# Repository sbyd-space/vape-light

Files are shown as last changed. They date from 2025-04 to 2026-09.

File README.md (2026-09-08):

# vape flashlight
An educational DIY kit for converting a disposable vape into a rechargeable flashlight

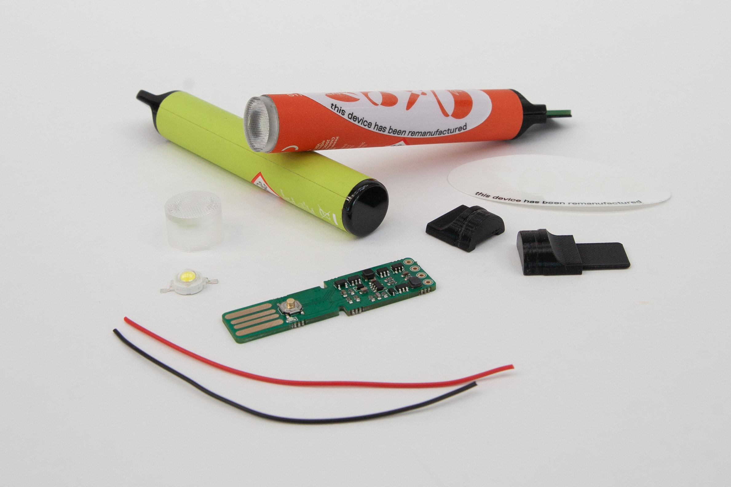
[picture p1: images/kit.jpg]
photograph of an early version of the kit

*early prototype of the kit photographed by Daniel Wilkens, used under CC BY 4.0 / cropped from original*

The kit is used in workshops to educate about:
* environmental and social impact of resource extraction
* resource consumption of electronics and disposable products
* basic hands-on soldering skills

It is accompanied by a [zine][zine] containing contextual information about these topics and instructions for assembly.

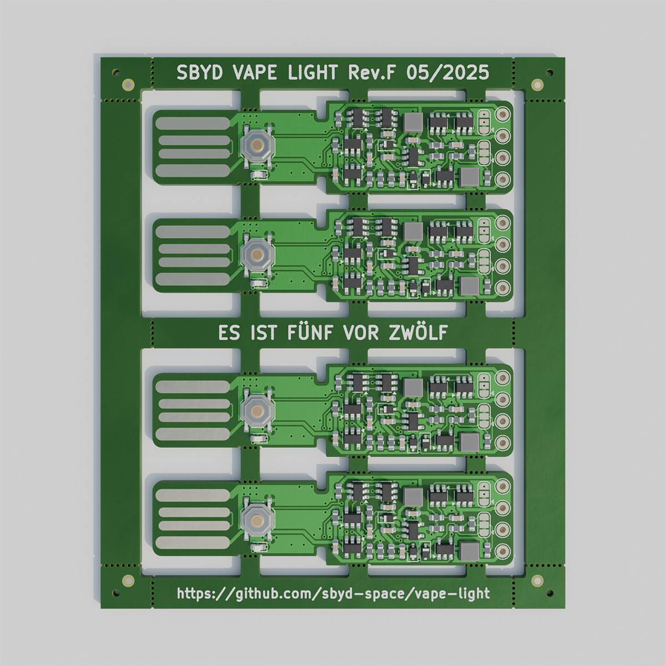
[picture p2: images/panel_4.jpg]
rendering of the pcb

*rendering of the pcb by Steffen Hartwig, licensed under CC BY 4.0*

The pcbs were developed with [KiCad 8.0][kicad].  
[KiKit 1.6.0][kikit] was used for the panelization of the PCBs for production.  
Visualizations were made with [Blender 4.2][blender] and [pcb2blender 2.15][pcb2blender].  
The fabrication files were generated with [Fabrication Toolkit 5.0.1][fabricationtoolkit].  
The files for 3D printing were generated from [OpenSCAD 2021.01][openscad].  

PCB and 3D printing source files are licensed under **CERN OHL P 2.0**  
Images and visualizations are licensed under **CC BY 4.0** 




The kit, workshop and zine were developed in the project ["Sustainability by Design"][sbyd] as part of the “Innovative University” funding line and is supported by the German Federal Ministry of Research, Technology and Space (BMFTR) and the Joint Science Conference (GWK).

[zine]: https://sbyd.space/wp-content/uploads/2024/09/SBYD-Zine_3_WEB.pdf
[sbyd]: https://sbyd.space/en/

[kicad]: https://www.kicad.org
[kikit]: https://github.com/yaqwsx/KiKit
[blender]: https://www.blender.org
[pcb2blender]: https://github.com/30350n/pcb2blender
[fabricationtoolkit]: https://github.com/bennymeg/JLC-Plugin-for-KiCad
[openscad]: https://openscad.org

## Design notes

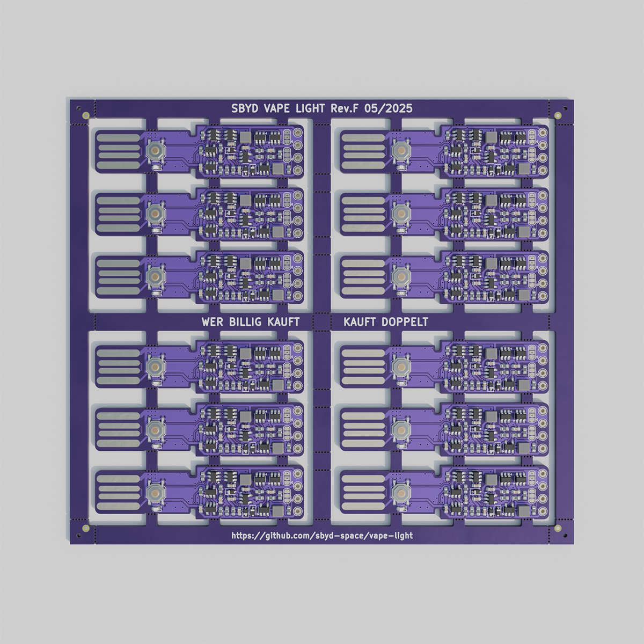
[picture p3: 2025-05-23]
images/panel_12.jpg

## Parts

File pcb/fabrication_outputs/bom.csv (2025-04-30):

Designator | Footprint | Quantity | Value | LCSC Part #
0-C1, 0-C6, 0-C7, 1-C1, 1-C6, 1-C7, 2-C1, 2-C6, 2-C7, 3-C1, 3-C6, 3-C7 | 0603 | 12 | 100n | C14663
0-C2, 1-C2, 2-C2, 3-C2 | 0603 | 4 | 1u | C15849
0-C3, 1-C3, 2-C3, 3-C3 | 0603 | 4 | 10u | C96446
0-C4, 1-C4, 2-C4, 3-C4 | 0603 | 4 | 150p | C1594
0-C5, 1-C5, 2-C5, 3-C5 | 0603 | 4 | 2u2 | C23630
0-D2, 1-D2, 2-D2, 3-D2 | 0603 | 4 | LED | C2286
0-D3, 0-D4, 0-D5, 1-D3, 1-D4, 1-D5, 2-D3, 2-D4, 2-D5, 3-D3, 3-D4, 3-D5 | D_SOD-323 | 12 | D_Schottky | C191023
0-L1, 1-L1, 2-L1, 3-L1 | L_3x3 | 4 | 47uH | C370426
0-L2, 1-L2, 2-L2, 3-L2 | L_3x3 | 4 | 10uH | C45403
0-Q1, 1-Q1, 2-Q1, 3-Q1 | SOT-23-6 | 4 | FS8205A | C2830320
0-R1, 1-R1, 2-R1, 3-R1 | 0603 | 4 | 180 | C22828
0-R10, 1-R10, 2-R10, 3-R10 | 0603 | 4 | 1 | C22936
0-R11, 1-R11, 2-R11, 3-R11 | 0603 | 4 | 330m | C2934252
0-R2, 1-R2, 2-R2, 3-R2 | 0603 | 4 | 5k6 | C23189
0-R3, 1-R3, 2-R3, 3-R3 | 0603 | 4 | 1k | C21190
0-R4, 1-R4, 2-R4, 3-R4 | 0603 | 4 | 100 | C22775
0-R5, 1-R5, 2-R5, 3-R5 | 0603 | 4 | 10k | C25804
0-R6, 1-R6, 2-R6, 3-R6 | 0603 | 4 | 680m | C5126049
0-R7, 1-R7, 2-R7, 3-R7 | 0603 | 4 | 13K | C22797
0-R8, 1-R8, 2-R8, 3-R8 | 0603 | 4 | 150k | C22807
0-R9, 1-R9, 2-R9, 3-R9 | 0603 | 4 | 10k | C25804
0-SW1, 1-SW1, 2-SW1, 3-SW1 | SW_Push_1P1T_XKB_TS-1187A | 4 | SW_Push | C571338
0-U1, 1-U1, 2-U1, 3-U1 | SOT-23-6 | 4 | DW01A | C2927799
0-U2, 1-U2, 2-U2, 3-U2 | SOT-23-5 | 4 | LTC4054ES5-4.2 | C478383
0-U3, 1-U3, 2-U3, 3-U3 | SOT-23-5 | 4 | LM27313XMF | C341750
0-U4, 1-U4, 2-U4, 3-U4 | SOT-23-6 | 4 | 74LVC2G14 | C5375976
0-U5, 1-U5, 2-U5, 3-U5 | SOT-23-6 | 4 | 74LVC1G175 | C128412
0-U6, 1-U6, 2-U6, 3-U6 | TSOT-23-5 | 4 | AL8860WT | C125330
0-U7, 1-U7, 2-U7, 3-U7 | SOT-23-5 | 4 | 74LVC1G02 | C16360

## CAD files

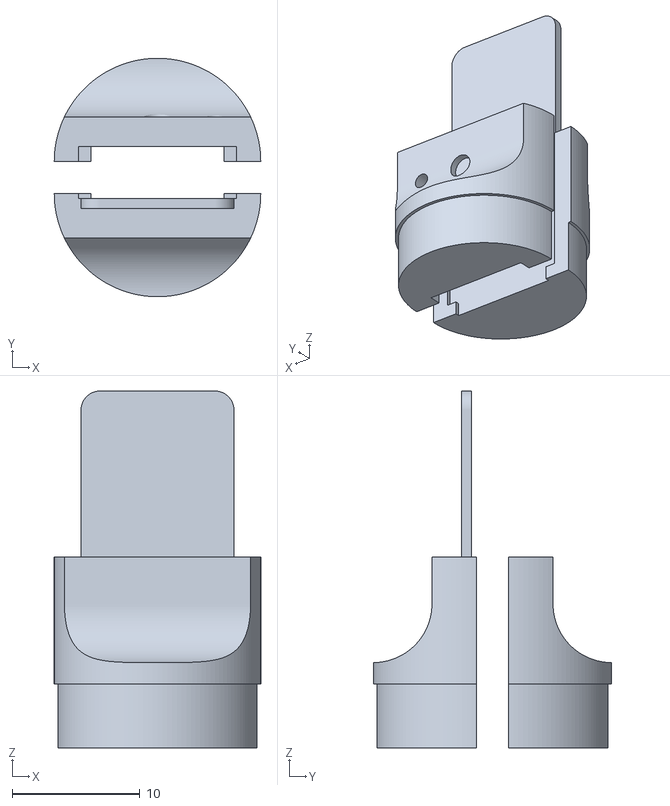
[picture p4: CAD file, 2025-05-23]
pcb/fabrication_outputs/vapelight.stl
16.2 x 18.7 x 28.0

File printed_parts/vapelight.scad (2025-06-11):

// for PCB revision F
// 06/2025

//part of https://github.com/sbyd-space/vape-light

//License: CC BY 4.0
//https://creativecommons.org/licenses/by/4.0/

$fn=128;  //resolution

h_lower=5; //length of lower part inside the tube
d_lower=15.6; //diameter of lower part inside the tube
thickness_end=7; //thickness of upper end

d_upper=16.2; //diameter of rim of upper part
r_fillet=(d_upper-thickness_end)/2; //radius of the big fillet
h_rim=1.7; //thickness of the rim sitting on the end of the tube
h_upper=10; //overall height of upper part

d_button=2.2; //diameter of button hole
h_button=6; //height of button above tube


 difference(){ //part 1
     union(){ //main body
        translate([0,0,0])cylinder(h=h_upper,r=d_upper/2); //upper part
        translate([0,0,-h_lower])cylinder(h=h_lower,r=d_lower/2); //lower part
    }
    translate([0,r_fillet+thickness_end/2,r_fillet+h_rim])rotate([0,90,0])translate([0,0,-50])cylinder(h=100,r=r_fillet); //cutter for big fillet
    translate([0,thickness_end/2,h_rim+r_fillet])translate([-50,0,0])cube([100,100,100]); //cutting cube above fillet

    //cutout for pcb:
    translate([-6.2,-.4,-3.75])cube([12.4,1.6,10+3.75]);
    translate([-5.2,-.4,-5])cube([10.4,1.6,1.5]);
    
        
    translate([0,0,h_button])rotate([-90,0,0])cylinder(h=d_upper/2,r=d_button/2); // cutout for button cap
    hull(){ // cutout for button body and legs
        translate([-1.6,1.2,h_button])rotate([-90,0,0])cylinder(h=1.6,r1=3.35,r2=2.6);
        translate([1.6,1.2,h_button])rotate([-90,0,0])cylinder(h=1.6,r1=3.35,r2=2.6);
    }
    translate([4.5,0,h_button])rotate([-90,0,0])cylinder(h=10,r=0.7);// cutout for led
    translate([4.5,1.2,h_button])rotate([-90,0,0])cylinder(h=1,r1=1.3, r2=0.7);// cutout for led body
    
    translate([-25,-50,-25])cube([50,50,50]); //cutter cube for unused half
}


 translate([0,-2.5,0])   //separate parts for printing 
 difference(){ //part 2
    union(){ //main body
        translate([0,0,0])cylinder(h=h_upper,r=d_upper/2); //upper part
        translate([0,0,-h_lower])cylinder(h=h_lower,r=d_lower/2); //lower part
        union() { //pcb support plate
            translate([-6,-1.2,h_upper])cube([12,.8,11.5]);   
            translate([-4.5,-1.2,h_upper])cube([9,.8,13]);  
            translate([-4.5,-1.2,h_upper+11.5])rotate([-90,0,0])cylinder(h=.8,r=1.5);  //radiussed corner
            translate([4.5,-1.2,h_upper+11.5])rotate([-90,0,0])cylinder(h=.8,r=1.5);   //radiussed corner
        }        
    }
    mirror([0,1,0]) { //mirrored from other side
        translate([0,r_fillet+thickness_end/2,r_fillet+h_rim])rotate([0,90,0])translate([0,0,-50])cylinder(h=100,r=r_fillet); //cutter for big fillet
        translate([0,thickness_end/2,h_rim+r_fillet])translate([-50,0,0])cube([100,100,100]); //cutting cube above fillet
    }
 
    //cutout for pcb:
    translate([-6.2,-.4,-3.75])cube([12.4,1.6,10+3.75]);
    translate([-5.2,-.4,-5])cube([10.4,1.6,1.5]);
    
    translate([-25,0,-25])cube([50,50,50]); //cutter cube for unused half
}

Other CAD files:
printed_parts/vapelight_e800.stl
printed_parts/vapelight_e600.stl
printed_parts/vapelight_e600.scad
printed_parts/vapelight_e800.scad

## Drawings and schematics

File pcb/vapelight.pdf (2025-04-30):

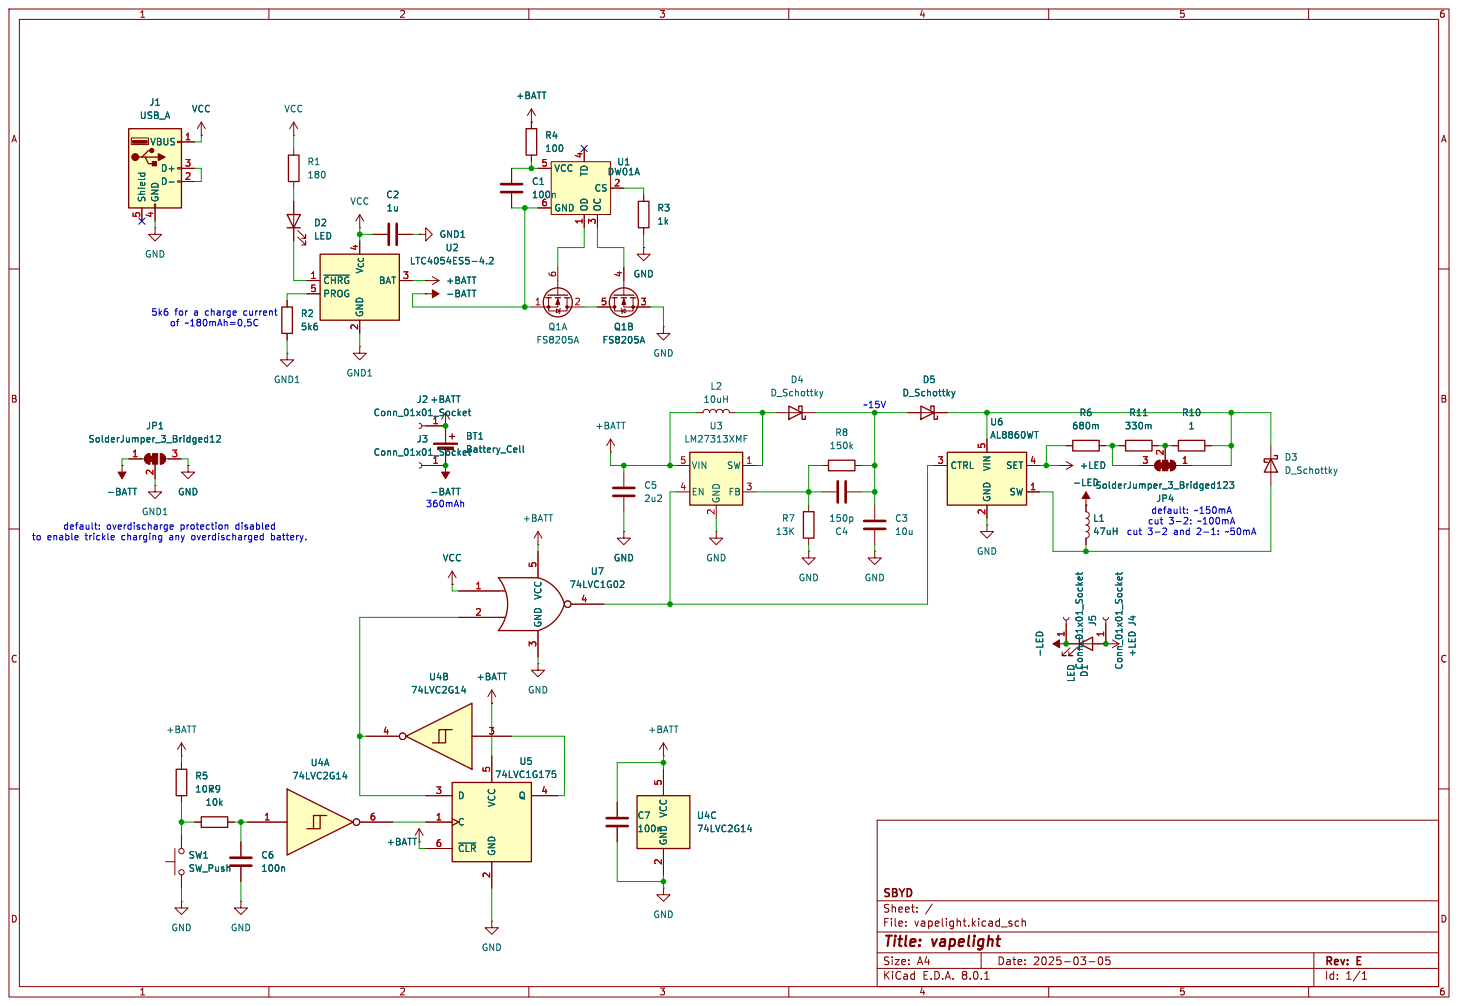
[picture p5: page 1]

5k6 for a charge current of ~180mAh=0,5C

Id: 1/1 Title: vapelight File: vapelight.kicad_sch Sheet: / SBYD

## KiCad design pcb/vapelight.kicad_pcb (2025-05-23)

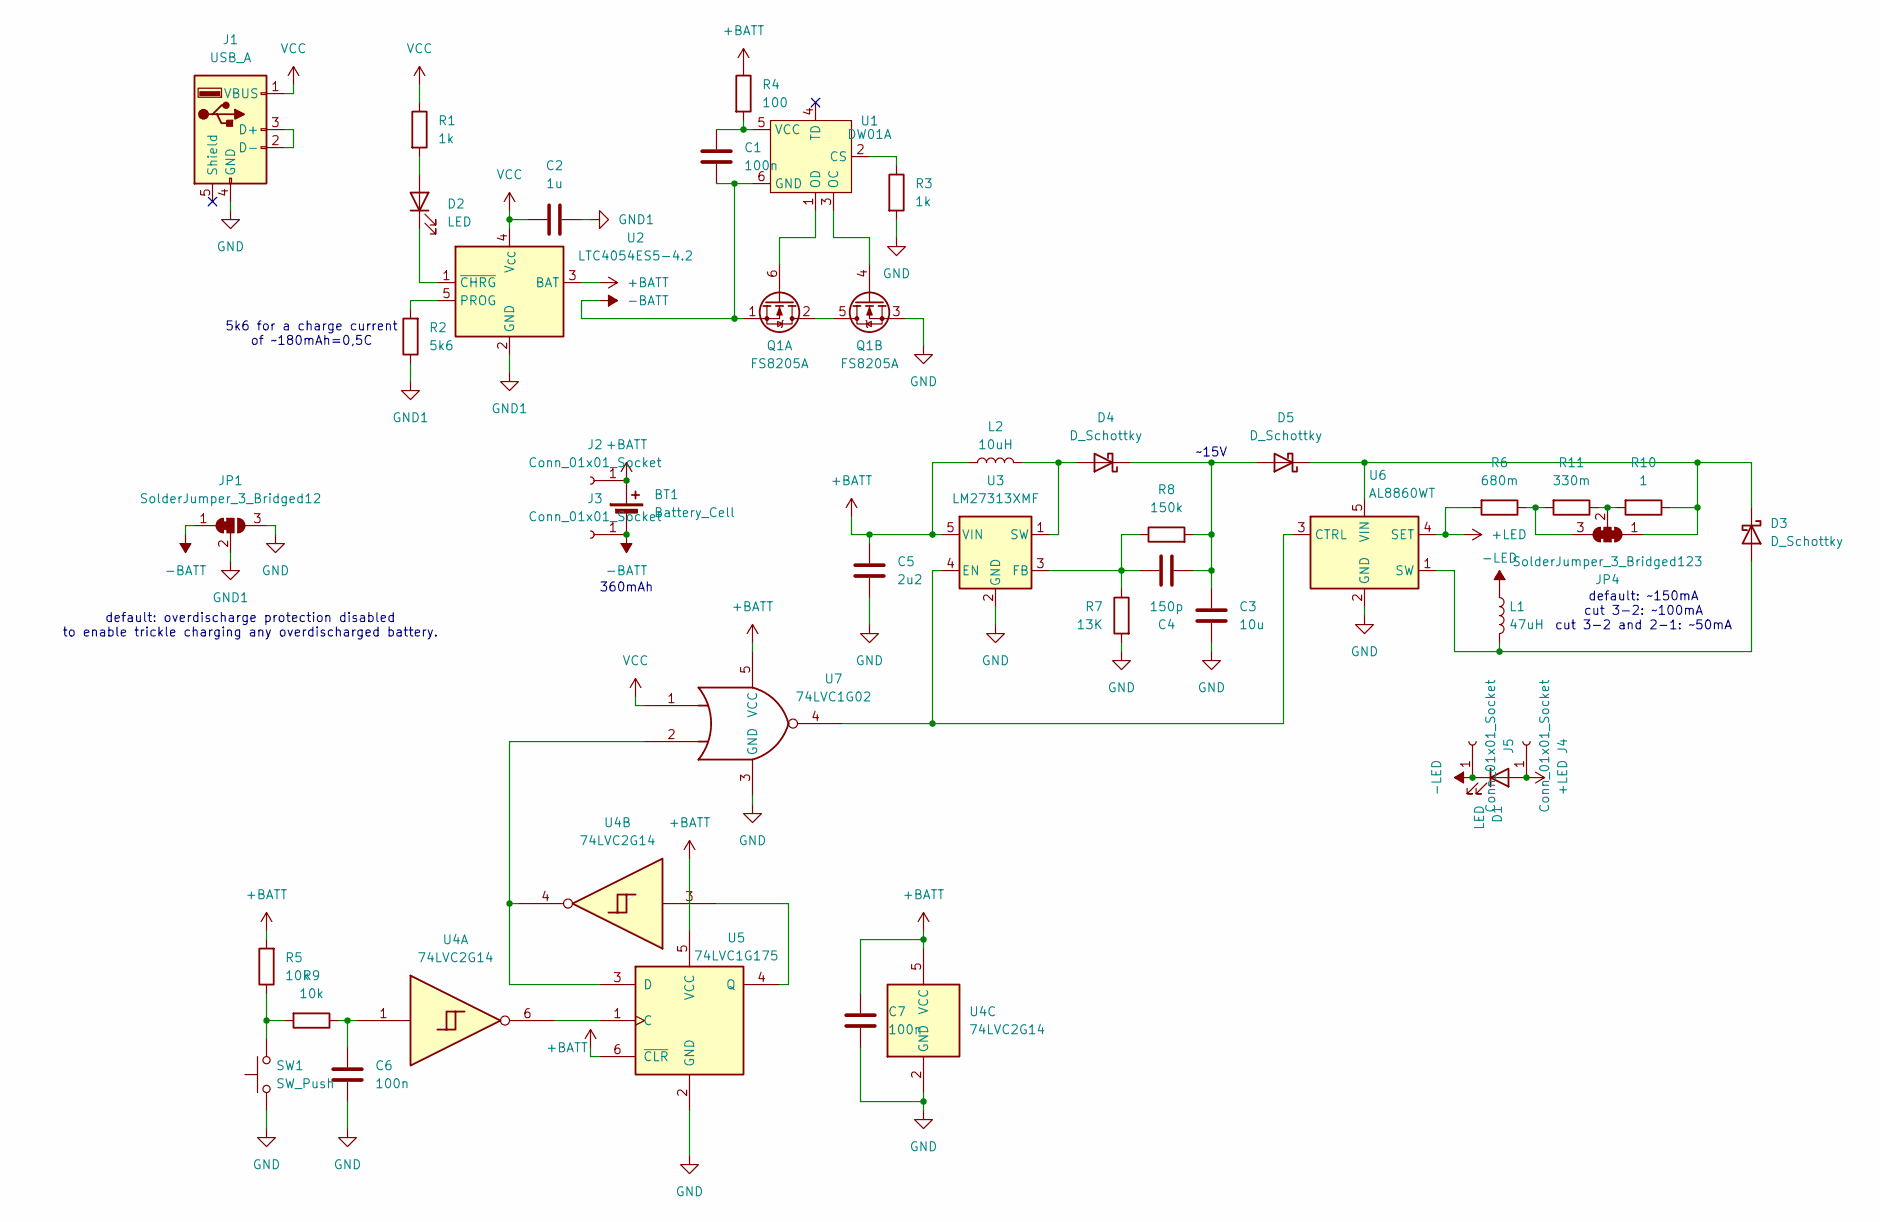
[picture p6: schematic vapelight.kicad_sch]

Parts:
BT1: Battery_Cell
C1, C6, C7: 100n; C_0603_1608Metric; LCSC C14663
C2: 1u; C_0603_1608Metric; LCSC C15849
C3: 10u; C_0603_1608Metric; LCSC C96446
C4: 150p; C_0603_1608Metric; LCSC C1594
C5: 2u2; C_0603_1608Metric; LCSC C23630
D1: LED
D2: LED; LED_0603_1608Metric; LCSC C2286
D3, D4, D5: D_Schottky; D_SOD-323; LCSC C191023
J1: USB_A; PCB_USB
J2, J3, J4, J5: Conn_01x01_Socket; Pin_D1.0mm_L10.0mm
JP1: SolderJumper_3_Bridged12; SolderJumper-3_P1.3mm_Bridged12_RoundedPad1.0x1.5mm
JP4: SolderJumper_3_Bridged123; SolderJumper-3_P1.3mm_Bridged123_RoundedPad1.0x1.5mm
L1: 47uH; L_3x3; LCSC C370426
L2: 10uH; L_3x3; LCSC C45403
Q1: FS8205A; SOT-23-6; LCSC C2830320
R1, R3: 1k; R_0603_1608Metric; LCSC C21190
R2: 5k6; R_0603_1608Metric; LCSC C23189
R4: 100; R_0603_1608Metric; LCSC C22775
R5, R9: 10k; R_0603_1608Metric; LCSC C25804
R6: 680m; R_0603_1608Metric; LCSC C5126049
R7: 13K; R_0603_1608Metric; LCSC C22797
R8: 150k; R_0603_1608Metric; LCSC C22807
R10: 1; R_0603_1608Metric; LCSC C22936
R11: 330m; R_0603_1608Metric; LCSC C2934252
SW1: SW_Push; SW_Push_1P1T_XKB_TS-1187A; LCSC C318886
U1: DW01A; SOT-23-6; LCSC C2927799
U2: LTC4054ES5-4.2; SOT-23-5; LCSC C478383
U3: LM27313XMF; SOT-23-5; LCSC C341750
U4: 74LVC2G14; SOT-23-6; LCSC C5375976
U5: 74LVC1G175; SOT-23-6; LCSC C128412
U6: AL8860WT; TSOT-23-5; LCSC C125330
U7: 74LVC1G02; SOT-23-5; LCSC C16360

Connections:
+BATT: BT1.1 (+), C5.1, C7.2, J2.1, L2.1, R4.1, R5.2, U2.3 (BAT), U3.5 (VIN), U4.5 (VCC), U5.5 (VCC), U5.6 (~CLR), U7.5 (VCC)
+LED: D1.2 (A), J4.1, R6.2, U6.4 (SET)
-BATT: BT1.2 (-), C1.2, J3.1, JP1.1 (A), Q1.1 (S1), U1.6 (GND)
-LED: D1.1 (K), J5.1, L1.1
GND: C3.2, C5.2, C6.1, C7.1, J1.4 (GND), JP1.3 (B), Q1.3 (S2), R3.2, R7.2, SW1.1, U3.2 (GND), U4.2 (GND), U5.2 (GND), U6.2 (GND), U7.3 (GND)
GND1: C2.2, JP1.2 (C), R2.1, U2.2 (GND)
unnamed: C6.2, R9.1, U4.1
unnamed: D2.2 (A), R1.2
unnamed: D2.1 (K), U2.1 (~CHRG)
unnamed: D3.2 (A), L1.2, U6.1 (SW)
unnamed: D3.1 (K), D5.1 (K), JP4.1 (A), R10.1, U6.5 (VIN)
unnamed: D4.2 (A), L2.2, U3.1 (SW)
unnamed: C3.1, C4.1, D4.1 (K), D5.2 (A), R8.2
unnamed: J1.2 (D-), J1.3 (D+)
unnamed: JP4.3 (B), R6.1, R11.2
unnamed: JP4.2 (C), R10.2, R11.1
unnamed: Q1.2 (D1), Q1.5 (D2)
unnamed: Q1.6 (G1), U1.1 (OD)
unnamed: Q1.4 (G2), U1.3 (OC)
unnamed: R5.1, R9.2, SW1.2
unnamed: R3.1, U1.2 (CS)
unnamed: C1.1, R4.2, U1.5 (VCC)
unnamed: R2.2, U2.5 (PROG)
unnamed: U3.4 (EN), U6.3 (CTRL), U7.4
unnamed: C4.2, R7.1, R8.1, U3.3 (FB)
unnamed: U4.6, U5.1 (C)
unnamed: U4.4, U5.3 (D), U7.2
unnamed: U4.3, U5.4 (Q)
VCC: C2.1, J1.1 (VBUS), R1.1, U2.4 (V_{CC}), U7.1

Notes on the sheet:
~15V
default: ~150mA cut 3-2: ~100mA cut 3-2 and 2-1: ~50mA
default: overdischarge protection disabled to enable trickle charging any overdischarged battery.
360mAh
5k6 for a charge current of ~180mAh=0,5C

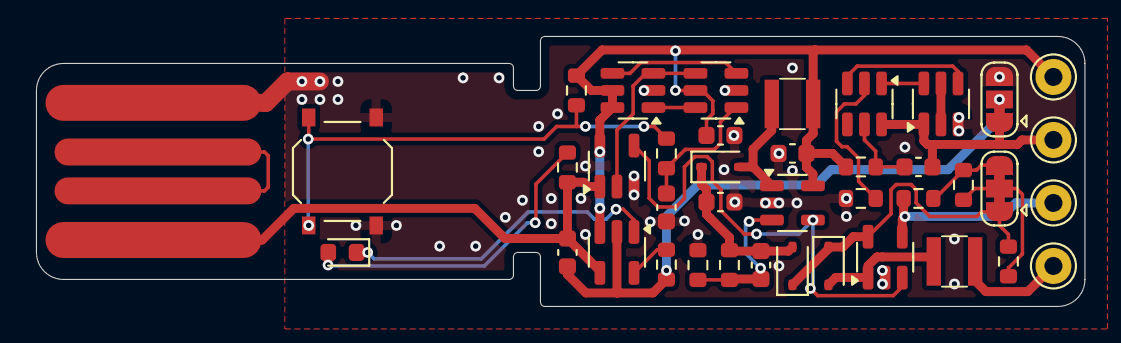
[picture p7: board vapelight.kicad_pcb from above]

Board: 2 copper layers, 58.2 x 15.0 mm, 40 parts (0 on the bottom side), 29 nets.

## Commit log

2025-04-30 Revision E
    [bom.csv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]
2025-05-08 updated and optimized images
    Switched to jpg: smaller files.
    Added photo of complete kit.
2025-05-23 Revision F
    – less bright charge LED
    – higher button
    – different sizes of panelized fabrication outputs
    - minor fixes
    [bom.csv, designators.csv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]
2025-06-11 optimized 3D printed part
    [vapelight.scad, vapelight.stl]
2026-02-20 added alternative printed part for elfbar 800
    [vapelight_e600.scad, vapelight_e600.stl, vapelight_e800.scad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]

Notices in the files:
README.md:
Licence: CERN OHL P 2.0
